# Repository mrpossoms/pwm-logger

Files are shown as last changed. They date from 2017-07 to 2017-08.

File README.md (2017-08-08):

# PWM Logger / Generator
logger

## Overview

The Protean PWM logger was designed to facilitate the development of hobbyist autonomous vehicle systems whose performance strongly depends on servo data collection and reproduction. The logger has the following default functions, but is fully reprogrammable.

* PWM signal generation for up to 6 channels.
* PMW signal decoding for up to 6 channels.
* Data access over I2C.

The PWM logger is built around Parallax's Propeller (P8X32A-Q44), an 8 core MCU which operates at ~20 MIPS per core. Dedicating each core's processing power to each servo channel offloads a potentially significant burden from your project's main computer. And allows for accurate decoding and generation of PWM signals.

## Usage

The PWM logger uses the I2C protocol for configuration and operation. It joins the bus as a slave device with the default 7-bit **address 0x69**. The logger is capable of, and tested with clock speeds of 100KHz and 400KHz but should be capable of higher speeds.

### Register usage

When configuring or using the PWM logger the first thing that your application will have to do is begin with an I2C write addressing the device and writing one byte which will select that register specifically. If you are planning on writing to the selected register you should continue with the current write transaction. Otherwise, end the transaction and follow up with a read.

### Device Registers

* 0x00 - Configuration register: Controls the mode of operation of the PWM logger. By default, the value in that register can have the following values.
   * 0 -> Echo off, this means the PWM logger will ignore PWM signals on the input channels. Instead it will generate the pulse width in the channel register.
   * 1 -> Echo on, this means the PWM logger will measure PWM signals on the input channels, and store the measurement in each channel register.
* 0x0N - Channel register: These registers store the pulse width as a pseudo time from [0, 255]. The pulse duration in seconds for a given channel register value can be obtained with the following operation (_value_ << 10) / _clock speed_ where the clock speed in the normal case is 8 * 10^7 Hz.
  * Once a channel register has been selected with a write, you can continue reading or writing multiple bytes as the selected register will be auto incremented. This allows you to collect data from, or write new timings to, all the servo channels in a single I2C transaction.
  * When the device is in echo mode the measured pulse widths are stored in each respective channel register.
  * When the device has echo mode disabled, the last pulse width in each channel register will be generated on that corresponding channel. That means writing to that register will cause the device to generate that particular pulse width.
* 0x0A - Firmware revision register: This register contains a single byte indicating the revision of the currently flashed firmware.
* 0x0B - Hardware reset register: Writing any value to this register will trigger a hardware reset of the board.

## Firmware

The PWM logger's firmware is written in PASM, the propeller's native language. More information about PASM can be found in the [propeller manual](https://www.parallax.com/sites/default/files/downloads/P8X32A-Web-PropellerManual-v1.2.pdf).

### Building & Flashing

For all platforms you will need to have Parallax's [SimpleIDE](http://learn.parallax.com/tutorials/language/propeller-c/propeller-c-set-simpleide) installed. It provides the necessary toolchain for assembling the source and flashing it to the propeller chip. You will also need a [Prop Plug](https://www.parallax.com/product/32201) to perform the actual flashing.

#### Mac / Linux

Once you have installed the SimpleIDE you will need to add the toolchain to your `PATH` environment variable. 

On MacOS the toolchain is likely to be found in `/Applications`. In my case, I was able to add it to my path like so.

```
export PATH="$PATH:/Applications/SimpleIDE.app/Contents/propeller-gcc/bin"
```

On linux, run the following command.

```
...
```

In both cases, you can make the change permanent by adding it to your `.bashrc` file (if bash is your shell).

After that, you should be ready to assemble the program and flash the board by using the following.

```
make flash
```

This will both assemble the program and flash the device. The program will run immediately. __Note:__ You may need to change the device file /dev/ttyUSB0 used in the Makefile to match the device file assigned to the Prop Plug on your system.

#### Windows

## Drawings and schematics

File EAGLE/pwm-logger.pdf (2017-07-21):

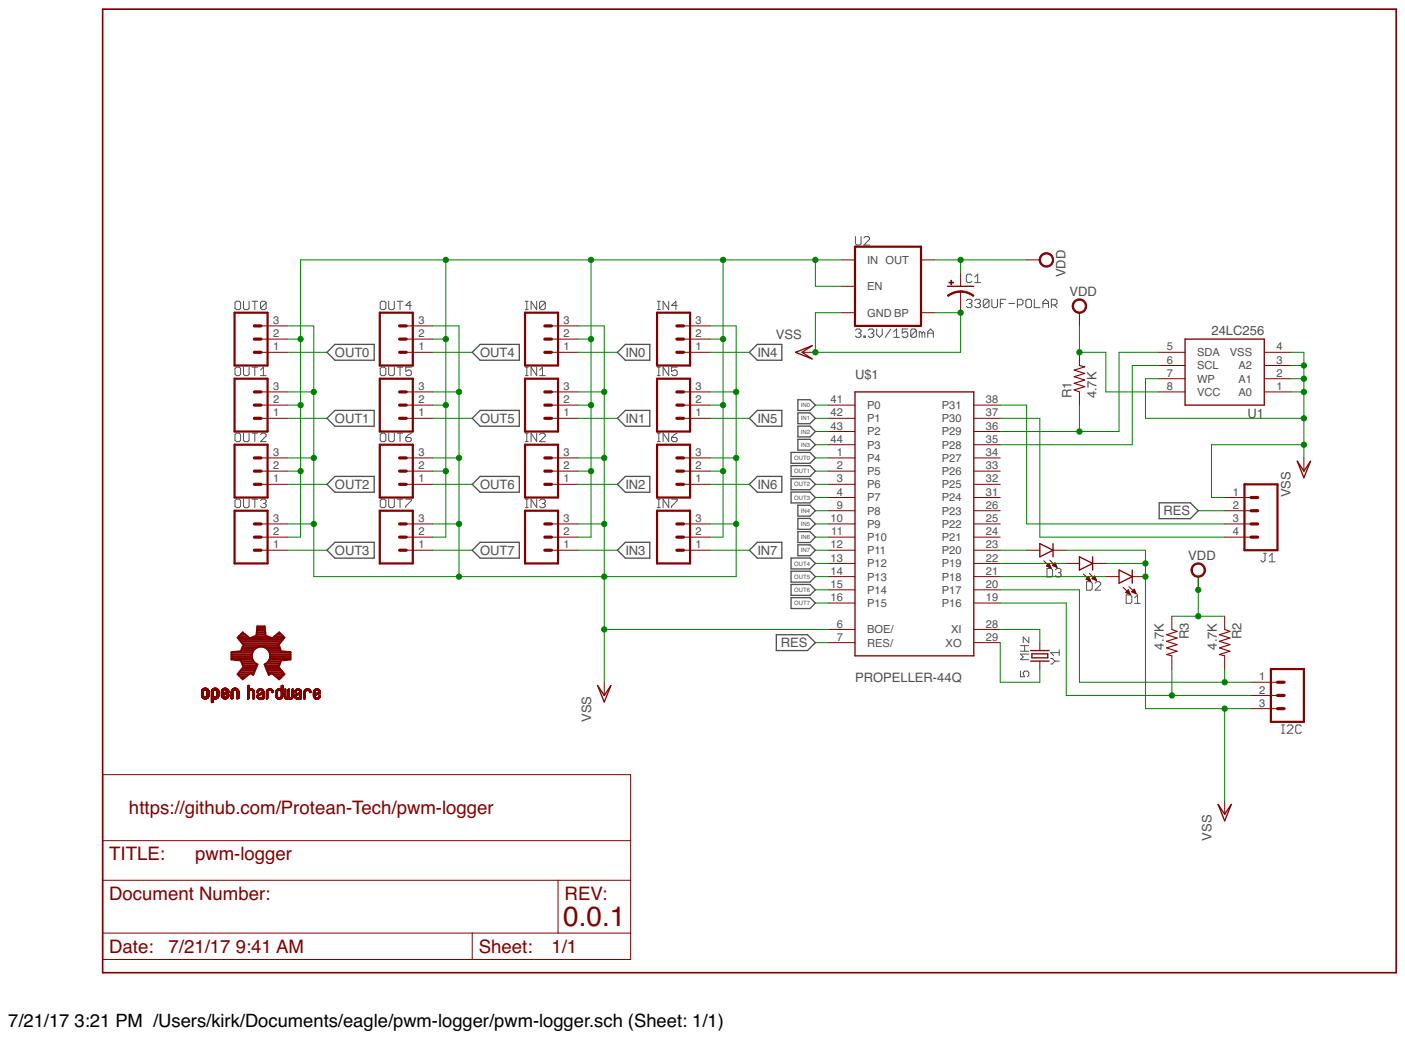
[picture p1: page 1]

35 P29
34 P28

https://github.com/Protean-Tech/pwm-logger

Document Number: | REV: 0.0.1

Date: 7/21/17 9:41 AM | Sheet: 1/1

7/21/17 3:21 PM /Users/kirk/Documents/eagle/pwm-logger/pwm-logger.sch (Sheet: 1/1)

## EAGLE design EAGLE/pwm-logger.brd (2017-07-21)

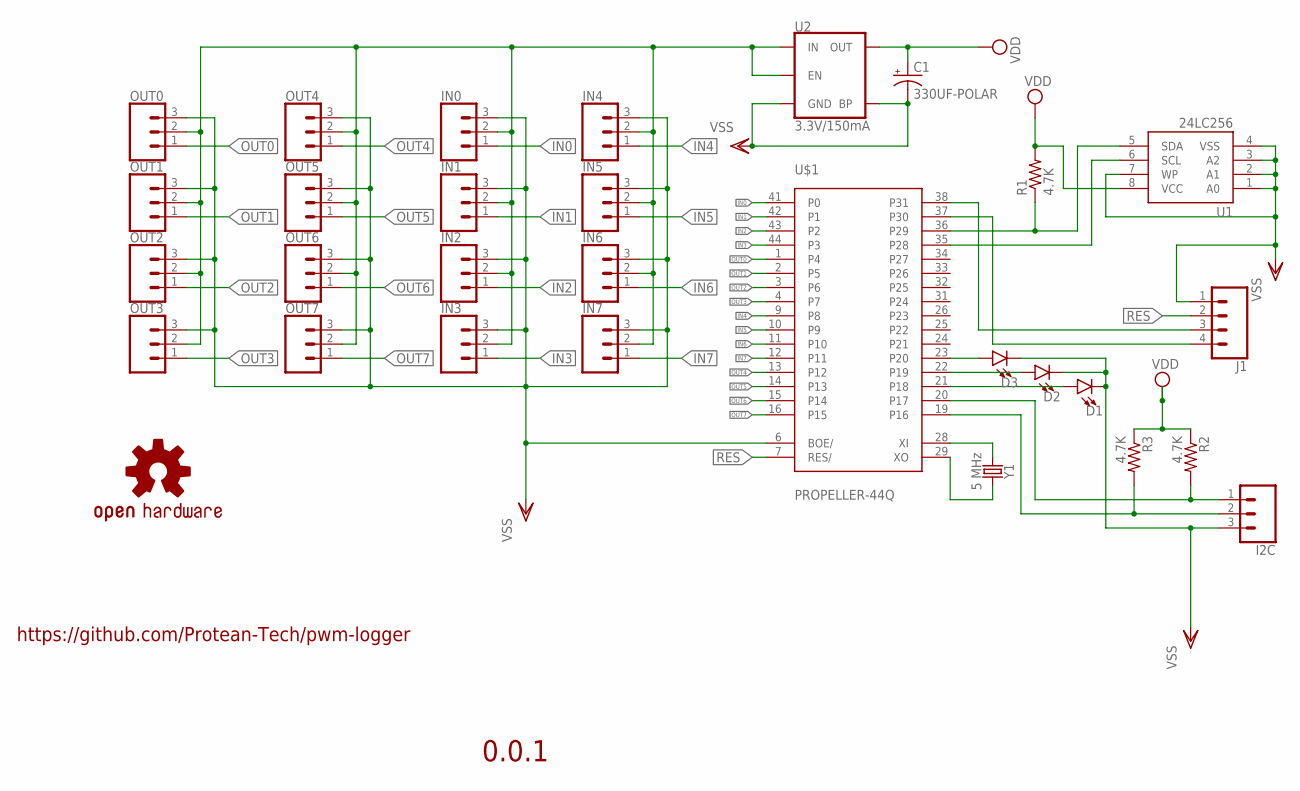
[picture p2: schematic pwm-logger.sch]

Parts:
C1: 330UF-POLAR; 1311
D1, D2, D3: LED-FKIT-1206; FKIT-LED-1206
I2C: CONN_03; 1X03
IN0, IN1, IN2, IN3, IN4, IN5, IN6, IN7: CONN_03; 1X03
J1: CONN_04; 1X04
LOGO1: OSHW-LOGOM; OSHW-LOGO-M
OUT0, OUT1, OUT2, OUT3, OUT4, OUT5, OUT6, OUT7: CONN_03; 1X03
R1, R2, R3: 4.7K; M2012
U1: 24LC256; SO08
U2: 3.3V/150mA; SOT23-5
U$1: PROPELLER-44Q; Q44
Y1: 5 MHz; HC49U

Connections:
IN0: IN0.1, U$1.41 (P0)
IN1: IN1.1, U$1.42 (P1)
IN2: IN2.1, U$1.43 (P2)
IN3: IN3.1, U$1.44 (P3)
IN4: IN4.1, U$1.9 (P8)
IN5: IN5.1, U$1.10 (P9)
IN6: IN6.1, U$1.11 (P10)
IN7: IN7.1, U$1.12 (P11)
unnamed: U$1.28 (XI), Y1.1
unnamed: U$1.29 (XO), Y1.2
unnamed: D3.A, U$1.23 (P20)
unnamed: D2.A, U$1.22 (P19)
unnamed: J1.3, U$1.38 (P31)
unnamed: D1.A, U$1.21 (P18)
unnamed: J1.4, U$1.37 (P30)
OUT0: OUT0.1, U$1.1 (P4)
OUT1: OUT1.1, U$1.2 (P5)
OUT2: OUT2.1, U$1.3 (P6)
OUT3: OUT3.1, U$1.4 (P7)
OUT4: OUT4.1, U$1.13 (P12)
OUT5: OUT5.1, U$1.14 (P13)
OUT6: OUT6.1, U$1.15 (P14)
OUT7: OUT7.1, U$1.16 (P15)
POWER_IN: IN0.2, IN1.2, IN2.2, IN3.2, IN4.2, IN5.2, IN6.2, IN7.2, OUT0.2, OUT1.2, OUT2.2, OUT3.2, OUT4.2, OUT5.2, OUT6.2, OUT7.2, U2.1 (IN), U2.3 (EN)
RES: J1.2, U$1.7 (RES/)
SCL: I2C.1, R2.2, U$1.20 (P17)
SCL_EEP: U1.6 (SCL), U$1.35 (P28)
SDA: I2C.2, R3.2, U$1.19 (P16)
SDA_EEP: R1.1, U1.5 (SDA), U$1.36 (P29)
VDD: C1.+, R1.2, R2.1, R3.1, U1.8 (VCC), U2.5 (OUT), U$1.8 (VDD), U$1.18 (VDD), U$1.30 (VDD), U$1.40 (VDD)
VSS: C1.-, D1.C, D2.C, D3.C, I2C.3, IN0.3, IN1.3, IN2.3, IN3.3, IN4.3, IN5.3, IN6.3, IN7.3, J1.1, OUT0.3, OUT1.3, OUT2.3, OUT3.3, OUT4.3, OUT5.3, OUT6.3, OUT7.3, U1.1 (A0), U1.2 (A1), U1.3 (A2), U1.4 (VSS), U1.7 (WP), U2.2 (GND), U2.4 (BP), U$1.5 (VSS), U$1.6 (BOE/), U$1.17 (VSS), U$1.27 (VSS), U$1.39 (VSS)

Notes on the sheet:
0.0.1
https://github.com/Protean-Tech/pwm-logger

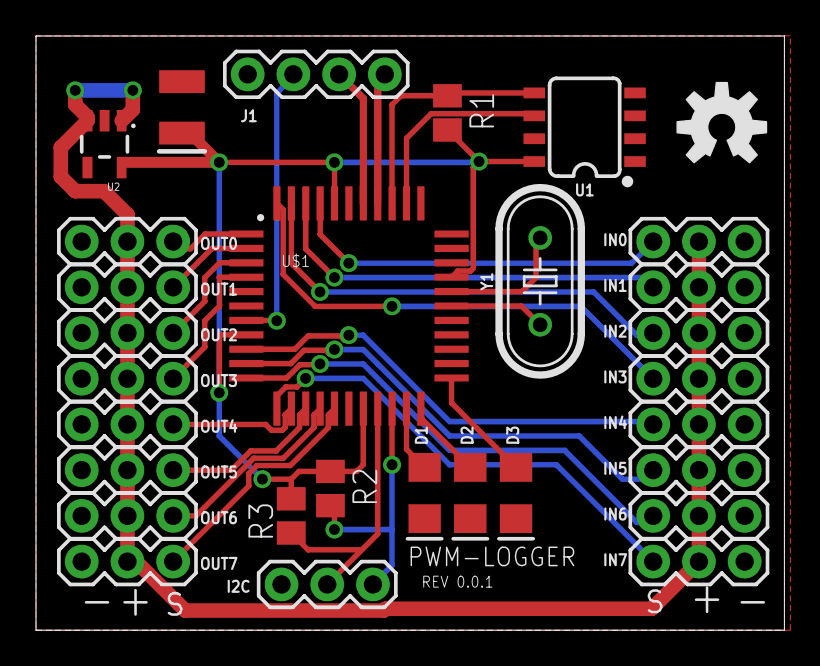
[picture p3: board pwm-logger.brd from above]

Board: 2 copper layers, 41.6 x 33.0 mm, 30 parts (0 on the bottom side), 31 nets.

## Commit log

2017-06-20 Working on i2c periph
2017-06-22 Working on i2c
2017-06-23 Simplified i2c code a bit
2017-06-23 Device addressing working
2017-06-30 Got I2C line conditions working correctly :D
2017-07-01 Echo is weird for some reason, but pwm generation seems initally stable
2017-07-03 Reading and writing the servo angle value over I2C is working :D
2017-07-03 Multiple servos on multiple cogs working
2017-07-10 Added schematics and design files
    [pwm-logger.brd, pwm-logger.sch]
2017-07-21 Updated schematics
    [pwm-logger.brd, pwm-logger.sch]
2017-08-01 Restructured the pwm-cog code a bit. Added version and reboot i2c registers
2017-08-01 Fixed I2C issues for board rev 0.0.1
2017-08-25 Added rotary encoder counter
2017-08-25 Missed encoder cog code
2017-09-02 Got rotory encoder functionality working
2017-09-10 Wheel encoder working

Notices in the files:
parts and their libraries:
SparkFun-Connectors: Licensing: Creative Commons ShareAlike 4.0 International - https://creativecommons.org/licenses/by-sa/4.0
